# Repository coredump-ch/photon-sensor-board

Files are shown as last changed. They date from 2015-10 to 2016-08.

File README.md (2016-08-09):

# Photon Sensor Board

A board to easily connect a Particle Photon with a DS18B20 temparature sensor.

The ``particle-boards`` library can be found here:
https://github.com/coredump-ch/kicad-particle

**Order here:**

- [DirtyPCBs](http://dirtypcbs.com/view.php?share=14221&accesskey=f6b3ffa6a66b2c59bf8eb13904b6e816)

## Screenshot

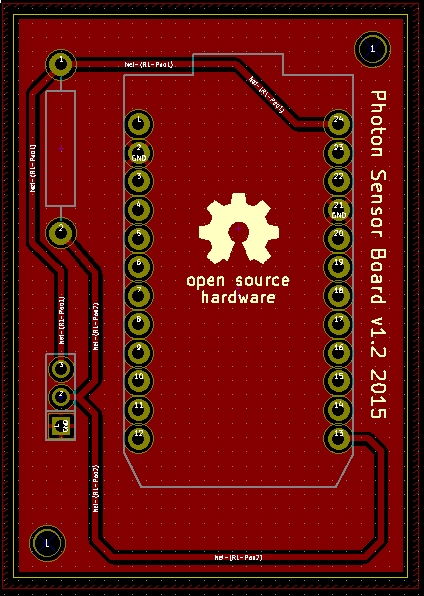
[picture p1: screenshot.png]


## PCB

DirtyPCB production:

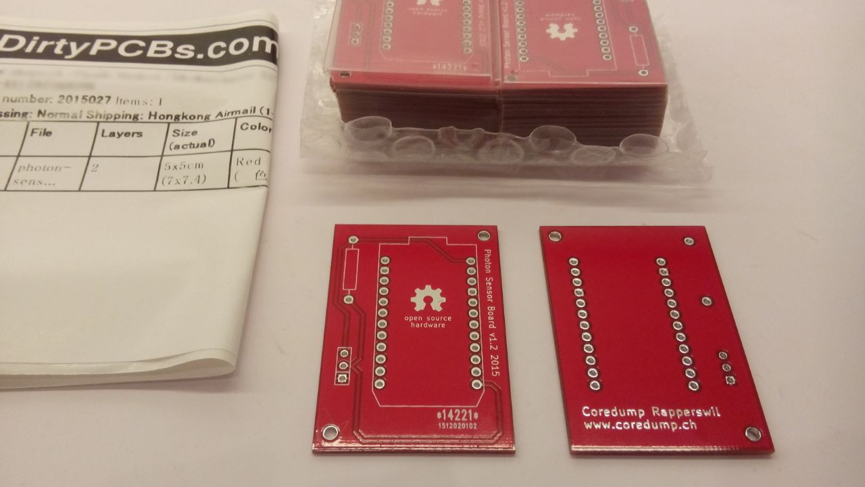
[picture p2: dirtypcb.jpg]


Poorly self etched PCB:

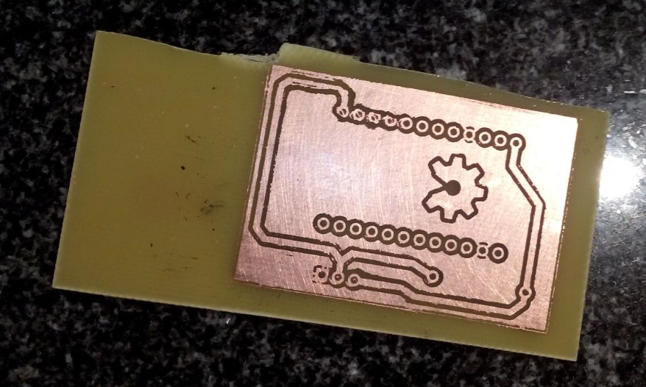
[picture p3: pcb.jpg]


## Assembly

- Solder 2x12 pin headers to the photon pins.
- Solder the resistor onto the board.
- Solder a DS18B20 sensor to the board using a cable / wire. Make sure it's long
  enough (<30cm) to prevent self-heating of the sensor.
  On the screenshot of the PCB above, the bottom pin is GND (blue), the middle
  one is Data (yellow) and the top pin is VDD (red). You can find the pin
  numbering of the sensor [here](http://mikroshop.ch/?gruppe=6&artikel=30).

## Firmware

https://github.com/coredump-ch/particle-ds18b20-firmware

## License

MIT

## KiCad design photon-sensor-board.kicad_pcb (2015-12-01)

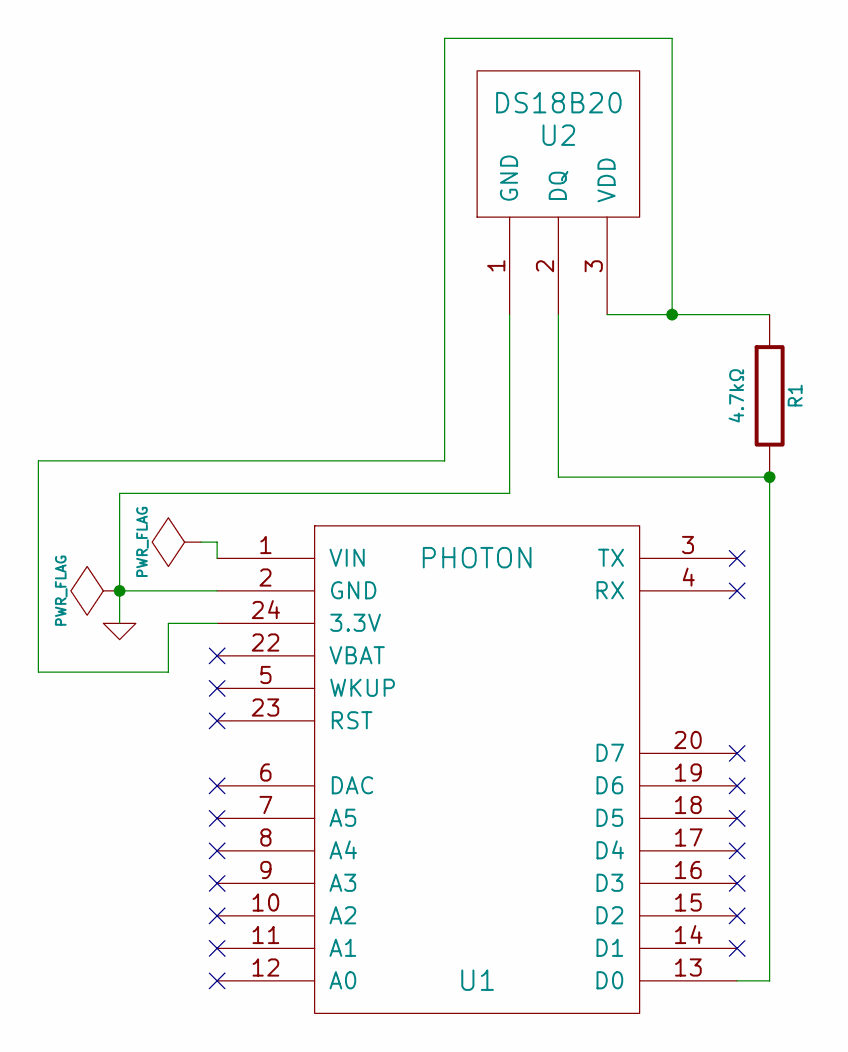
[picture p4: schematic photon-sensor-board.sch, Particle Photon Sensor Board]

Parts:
R1: 4.7kΩ
U1: PHOTON
U2: DS18B20

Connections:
GND: U1.2 (GND), U1.21, U2.1 (GND)
unnamed: R1.1, U1.24 (3.3V), U2.3 (VDD)
unnamed: R1.2, U1.13 (D0), U2.2 (DQ)

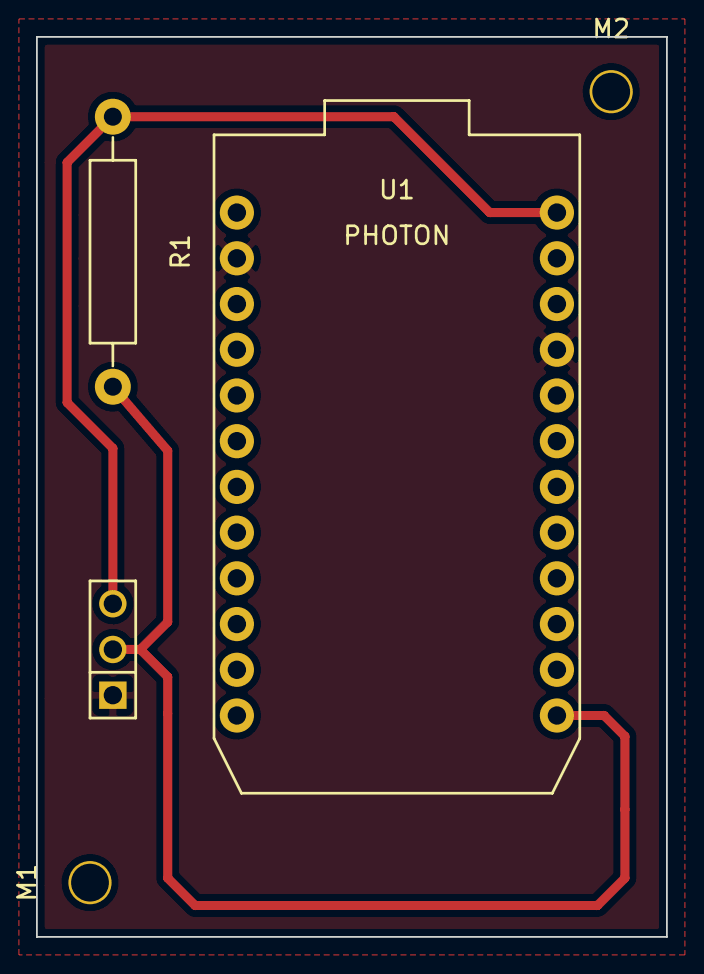
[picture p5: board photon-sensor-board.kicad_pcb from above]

Board: 2 copper layers, 35.0 x 50.0 mm, 5 parts (0 on the bottom side), 3 nets.

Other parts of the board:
M1, M2: MountingHole_2-5mm

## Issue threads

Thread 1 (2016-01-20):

Make it possible to disconnect sensor

dbrgn, 2016-01-20:
The sensor can heat up if it is under constant load.

Instead, connect it to the Photon through something like a transistor so it can be turned on and off.

rnestler, 2016-01-20:
Isn't it a digital sensor? I should support some kind of sleep mode then were it doesn't heat up.

dbrgn, 2016-01-21:
Yes, it's one-wire. A measurement only takes place when we ask for it, but apparently just having power applied could still heat it a little.

I'm not completely sure though, I just want to rule out all possibilities of self heating.

The worst self-heating factor was the distance from the board. When connecting a sensor directly to the PCB, the readings are 4-5°C higher than they should be. On contrast if you put a 10cm wire between the sensor and the board, they're mostly accurate.

Another factor is that we're polling quite frequently. For the water temperature sensors that won't be a problem, as we'll only poll them hourly or so. But when polling every 2-3 seconds, it can probably heat up from the load.

Here are some interesting links:

http://arduino.stackexchange.com/questions/789/my-ds18b20-is-reading-high-how-can-i-get-it-to-return-the-correct-temperature

http://forum.arduino.cc/index.php?topic=214113.0

dbrgn, 2016-01-21:
This is also interesting, wasn't aware of that:

> You need one inside a metal package if you want to measure air temperature, otherwise they pick up radiant heat from nearby objects (people) and read upto several degrees out - air temperature measurement is confounded by the radiant  heating.
>
> Black bodies absorb heat radiation efficiently, metals don't.

(From the Arduino thread)

rnestler, 2016-01-21:
Yes measuring temperature isn't easy....

Regarding the self heating: We could also mathematically compensate it if we can determine it precisely enough.

dbrgn, 2016-01-21:
I think the main thing we should do is testing.

Do you have calibrated, reliable, standalone temperature sensors at Sensi that could be used for comparison and testing? Then we could test things like distance from the PCB, frequency of polling, etc.

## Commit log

2015-10-02 Added mounting holes
    [photon-sensor-board.kicad_pcb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]
2015-10-03 Upgraded project for KiCad 2015-10-02 BZR 6241
    [photon-sensor-board.kicad_pcb, photon-sensor-board.sch]
2015-10-03 Updated netlist
    [photon-sensor-board.kicad_pcb]
2015-10-03 Removed border around mounting holes
    [photon-sensor-board.kicad_pcb]
2015-10-03 Adjusted OSHW text
    [photon-sensor-board.kicad_pcb]
2015-10-04 Updated some footprints with new libraries
    [photon-sensor-board.kicad_pcb]
2015-10-04 Some adjustments
    [photon-sensor-board.kicad_pcb, photon-sensor-board.sch]
2015-10-04 Added selfetch version
    [photon-sensor-board-selfetch.kicad_pcb, photon-sensor-board.kicad_pcb]
2015-10-15 Added PCB pic
2015-12-01 Exported v1.2
    [photon-sensor-board-B.Cu.gbl, photon-sensor-board-B.Mask.gbs, photon-sensor-board-B.SilkS.gbo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]
2016-01-11 Added DirtyPCB photo and assembly instructions
2016-07-19 Update README.md
    Sensor should *not* be soldered directly onto the board.
